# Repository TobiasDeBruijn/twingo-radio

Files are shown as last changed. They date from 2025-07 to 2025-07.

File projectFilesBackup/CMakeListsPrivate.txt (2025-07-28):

# !!! WARNING !!! AUTO-GENERATED FILE, PLEASE DO NOT MODIFY IT AND USE
# https://docs.platformio.org/page/projectconf/section_env_build.html#build-flags
#
# If you need to override existing CMake configuration or add extra,
# please create `CMakeListsUser.txt` in the root of project.
# The `CMakeListsUser.txt` will not be overwritten by PlatformIO.

set(CMAKE_CONFIGURATION_TYPES "nano_every" CACHE STRING "Build Types reflect PlatformIO Environments" FORCE)

# Convert "Home Directory" that may contain unescaped backslashes on Windows

SET(CMAKE_C_COMPILER "$ENV{HOME}/.platformio/packages/toolchain-atmelavr/bin/avr-gcc")
SET(CMAKE_CXX_COMPILER "$ENV{HOME}/.platformio/packages/toolchain-atmelavr/bin/avr-g++")
SET(CMAKE_CXX_FLAGS "-std=gnu++11 -fno-exceptions -fno-threadsafe-statics -fpermissive -Wno-error=narrowing -mmcu=atmega4809 -Os -w -ffunction-sections -fdata-sections -flto")
SET(CMAKE_C_FLAGS "-std=gnu11 -fno-fat-lto-objects -mmcu=atmega4809 -Os -w -ffunction-sections -fdata-sections -flto")

SET(CMAKE_C_STANDARD 11)
set(CMAKE_CXX_STANDARD 11)

if (CMAKE_BUILD_TYPE MATCHES "nano_every")
    add_definitions(-DPLATFORMIO=60002)
    add_definitions(-DARDUINO_AVR_NANO_EVERY)
    add_definitions(-DAVR_NANO_4809_328MODE)
    add_definitions(-DMILLIS_USE_TIMERB3)
    add_definitions(-DNO_EXTERNAL_I2C_PULLUP)
    add_definitions(-DF_CPU=16000000L)
    add_definitions(-DARDUINO_ARCH_MEGAAVR)
    add_definitions(-DARDUINO=10808)
    add_definitions(-DUSB_VID=0x2341)
    add_definitions(-DUSB_PID=0x0058)
    add_definitions(-DUSB_PRODUCT=\"Arduino\ Nano\ Every\")
    add_definitions(-DUSB_MANUFACTURER=\"Arduino\")

    include_directories("${CMAKE_CURRENT_LIST_DIR}/include")
    include_directories("${CMAKE_CURRENT_LIST_DIR}/src")
    include_directories("$ENV{HOME}/.platformio/packages/framework-arduino-megaavr/cores/arduino/api/deprecated")
    include_directories("$ENV{HOME}/.platformio/packages/framework-arduino-megaavr/cores/arduino")
    include_directories("$ENV{HOME}/.platformio/packages/framework-arduino-megaavr/variants/nona4809")
    include_directories("$ENV{HOME}/.platformio/packages/framework-arduino-megaavr/libraries/EEPROM/src")
    include_directories("$ENV{HOME}/.platformio/packages/framework-arduino-megaavr/libraries/SPI/src")
    include_directories("$ENV{HOME}/.platformio/packages/framework-arduino-megaavr/libraries/SoftwareSerial/src")
    include_directories("$ENV{HOME}/.platformio/packages/framework-arduino-megaavr/libraries/Wire/src")
    include_directories("$ENV{HOME}/.platformio/packages/toolchain-atmelavr/lib/gcc/avr/7.3.0/include")
    include_directories("$ENV{HOME}/.platformio/packages/toolchain-atmelavr/lib/gcc/avr/7.3.0/include-fixed")
    include_directories("$ENV{HOME}/.platformio/packages/toolchain-atmelavr/avr/include")

    FILE(GLOB_RECURSE EXTRA_LIB_SOURCES
        ${CMAKE_CURRENT_LIST_DIR}/.pio/libdeps/nano_every/*.*
    )
endif()

FILE(GLOB_RECURSE SRC_LIST
    ${CMAKE_CURRENT_LIST_DIR}/src/*.*
    ${CMAKE_CURRENT_LIST_DIR}/lib/*.*
    ${CMAKE_CURRENT_LIST_DIR}/test/*.*
)

list(APPEND SRC_LIST ${EXTRA_LIB_SOURCES})

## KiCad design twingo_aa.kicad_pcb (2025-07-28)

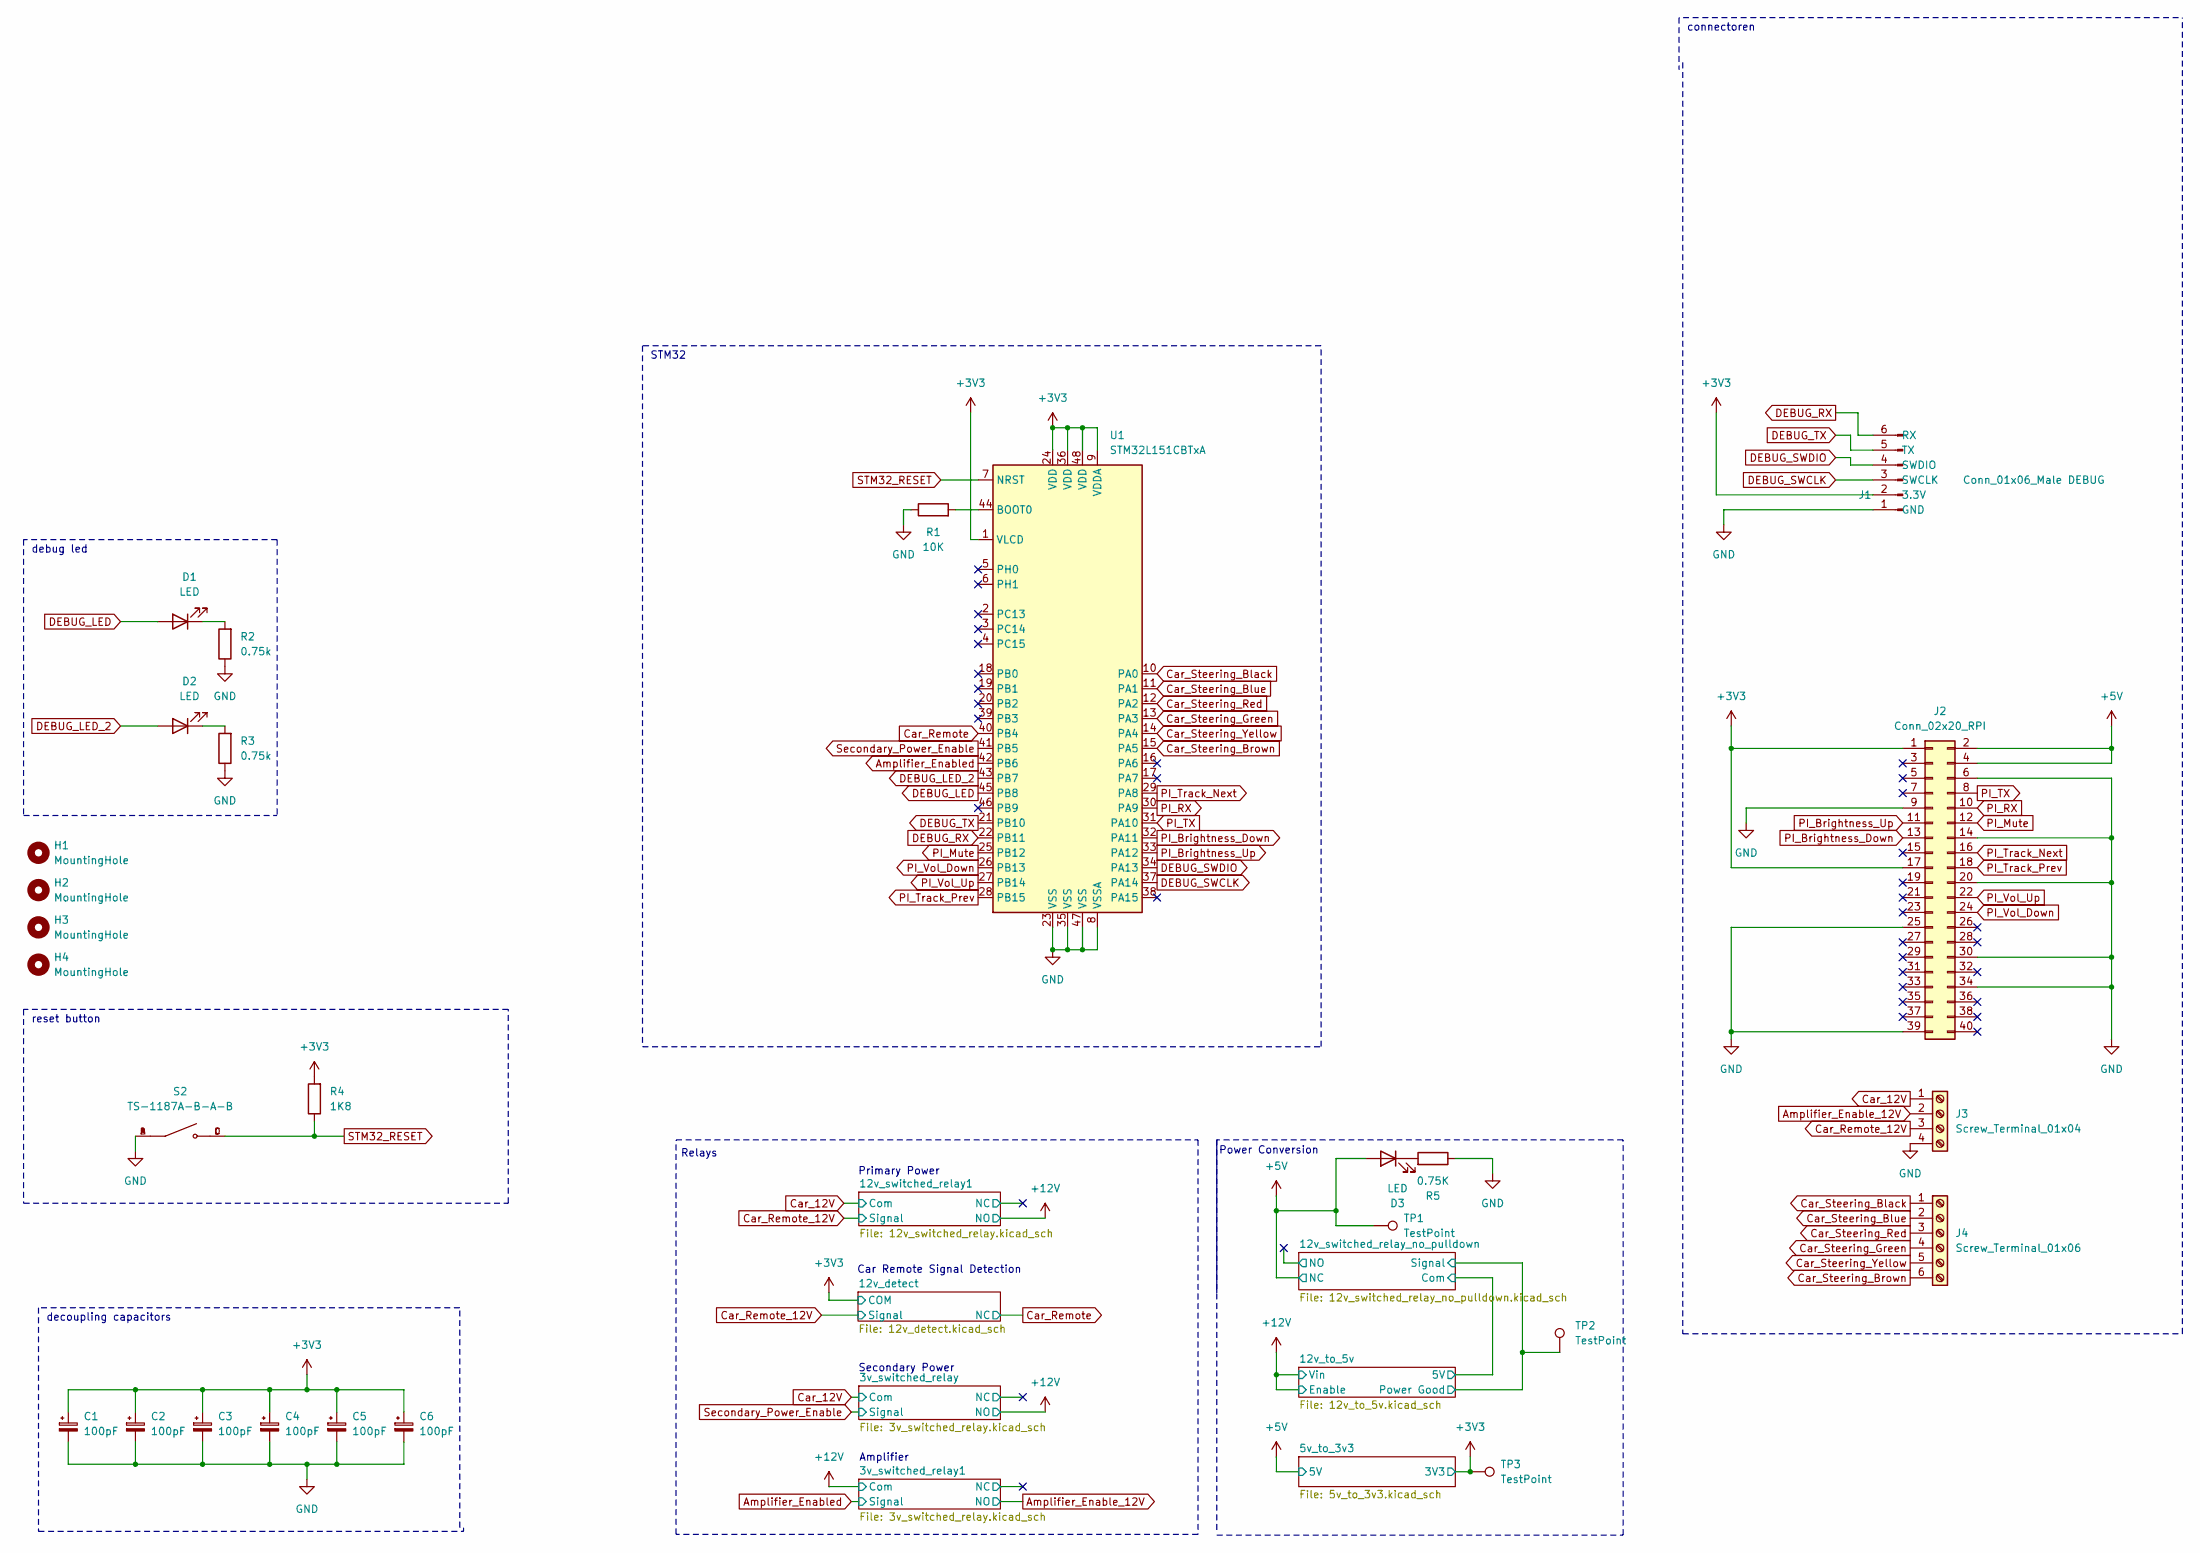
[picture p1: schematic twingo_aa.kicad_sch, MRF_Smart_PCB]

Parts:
C1, C2, C3, C4, C5, C6: 100pF; C_0805_2012Metric
D1, D2, D3: LED; LED_0805_2012Metric
H1, H2, H3, H4: MountingHole; MountingHole_2.5mm
J1: Conn_01x06_Male DEBUG; JST_SHL_SM06B-SHLS-TF_1x06-1MP_P1.00mm_Horizontal
J2: Conn_02x20_RPI; PinSocket_2x20_P2.54mm_Vertical
J3: Screw_Terminal_01x04; TerminalBlock_bornier-4_P5.08mm
J4: Screw_Terminal_01x06; TerminalBlock_bornier-6_P5.08mm
R1: 10K; R_1206_3216Metric
R2, R3: 0.75k; R_0603_1608Metric
R4: 1K8; R_0603_1608Metric
R5: 0.75K; R_0805_2012Metric
S2: TS-1187A-B-A-B; SW_TS-1187A-B-A-B; PARTREV A0
TP1, TP2, TP3: TestPoint; TestPoint_Pad_D1.0mm
U1: STM32L151CBTxA; LQFP-48_7x7mm_P0.5mm

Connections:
+3V3: C1.1, C2.1, C3.1, C4.1, C5.1, C6.1, J1.2 (3.3V), J2.1, J2.17, R4.2, TP3.1, U1.1 (VLCD), U1.9 (VDDA), U1.24 (VDD), U1.36 (VDD), U1.48 (VDD); also elsewhere on the board
+5V: D3.2 (A), J2.2, J2.4, TP1.1; also elsewhere on the board
/12v_switched_relay_no_pulldown/Signal: TP2.1; also elsewhere on the board
Amplifier_Enable_12V: J3.2; also elsewhere on the board
Amplifier_Enabled: U1.42 (PB6); also elsewhere on the board
Car_12V: J3.1; also elsewhere on the board
Car_Remote: U1.40 (PB4); also elsewhere on the board
Car_Remote_12V: J3.3; also elsewhere on the board
Car_Steering_Black: J4.1, U1.10 (PA0)
Car_Steering_Blue: J4.2, U1.11 (PA1)
Car_Steering_Brown: J4.6, U1.15 (PA5)
Car_Steering_Green: J4.4, U1.13 (PA3)
Car_Steering_Red: J4.3, U1.12 (PA2)
Car_Steering_Yellow: J4.5, U1.14 (PA4)
DEBUG_LED: D1.2 (A), U1.45 (PB8)
DEBUG_LED_2: D2.2 (A), U1.43 (PB7)
DEBUG_RX: J1.6 (RX), U1.22 (PB11)
DEBUG_SWCLK: J1.3 (SWCLK), U1.37 (PA14)
DEBUG_SWDIO: J1.4 (SWDIO), U1.34 (PA13)
DEBUG_TX: J1.5 (TX), U1.21 (PB10)
GND: C1.2, C2.2, C3.2, C4.2, C5.2, C6.2, J1.1 (GND), J2.6, J2.9, J2.14, J2.20, J2.25, J2.30, J2.34, J2.39, J3.4, R1.1, R2.1, R3.1, R5.1, S2.A, S2.B, U1.8 (VSSA), U1.23 (VSS), U1.35 (VSS), U1.47 (VSS); also elsewhere on the board
unnamed: D1.1 (K), R2.2
unnamed: D2.1 (K), R3.2
unnamed: D3.1 (K), R5.2
unnamed: R1.2, U1.44 (BOOT0)
PI_Brightness_Down: J2.13, U1.32 (PA11)
PI_Brightness_Up: J2.11, U1.33 (PA12)
PI_Mute: J2.12, U1.25 (PB12)
PI_RX: J2.10, U1.30 (PA9)
PI_TX: J2.8, U1.31 (PA10)
PI_Track_Next: J2.16, U1.29 (PA8)
PI_Track_Prev: J2.18, U1.28 (PB15)
PI_Vol_Down: J2.24, U1.26 (PB13)
PI_Vol_Up: J2.22, U1.27 (PB14)
STM32_RESET: R4.1, S2.C, S2.D, U1.7 (NRST)
Secondary_Power_Enable: U1.41 (PB5); also elsewhere on the board

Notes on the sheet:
decoupling capacitors
Relays
Amplifier
Car Remote Signal Detection
Secondary Power
Power Conversion
debug led
STM32
Primary Power
reset button
connectoren

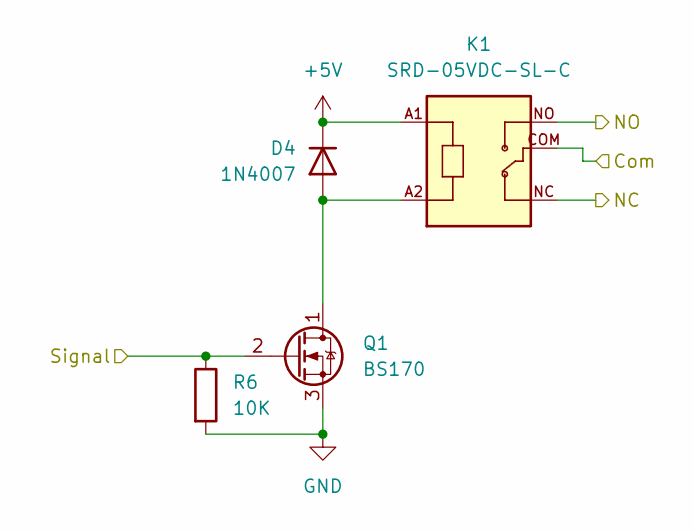
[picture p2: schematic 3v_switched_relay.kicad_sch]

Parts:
D4: 1N4007; D_DO-41_SOD81_P10.16mm_Horizontal
K1: SRD-05VDC-SL-C; RELAY_SRD-05VDC-SL-C
Q1: BS170; TO-92_Inline
R6: 10K; R_1206_3216Metric

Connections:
+5V: D4.1 (K), K1.A1; also elsewhere on the board
+12V: K1.NO; also elsewhere on the board
/3v_switched_relay/NC: K1.NC
Car_12V: K1.COM; also elsewhere on the board
GND: Q1.3 (S), R6.2; also elsewhere on the board
unnamed: D4.2 (A), K1.A2, Q1.1 (D)
Secondary_Power_Enable: Q1.2 (G), R6.1; also elsewhere on the board

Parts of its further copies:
D5: 1N4007; D_DO-41_SOD81_P10.16mm_Horizontal
K2: SRD-05VDC-SL-C; RELAY_SRD-05VDC-SL-C
Q2: BS170; TO-92_Inline
R7: 10K; R_1206_3216Metric

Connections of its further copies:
+5V: D5.1 (K), K2.A1; also elsewhere on the board
+12V: K2.COM; also elsewhere on the board
/3v_switched_relay1/NC: K2.NC
Amplifier_Enable_12V: K2.NO; also elsewhere on the board
Amplifier_Enabled: Q2.2 (G), R7.1; also elsewhere on the board
GND: Q2.3 (S), R7.2; also elsewhere on the board
unnamed: D5.2 (A), K2.A2, Q2.1 (D)

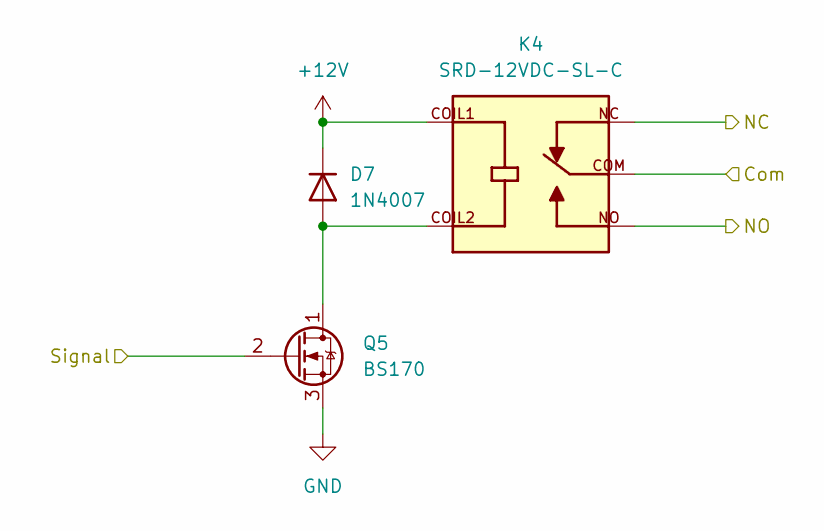
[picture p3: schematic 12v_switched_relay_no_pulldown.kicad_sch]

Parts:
D7: 1N4007; D_DO-41_SOD81_P10.16mm_Horizontal
K4: SRD-12VDC-SL-C; RELAY_SRD-12VDC-SL-C; PARTREV 1.0
Q5: BS170; TO-92_Inline

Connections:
+5V: K4.NC; also elsewhere on the board
+12V: D7.1 (K), K4.COIL1; also elsewhere on the board
/12v_switched_relay_no_pulldown/Com: K4.COM; also elsewhere on the board
/12v_switched_relay_no_pulldown/NO: K4.NO
/12v_switched_relay_no_pulldown/Signal: Q5.2 (G); also elsewhere on the board
GND: Q5.3 (S); also elsewhere on the board
unnamed: D7.2 (A), K4.COIL2, Q5.1 (D)

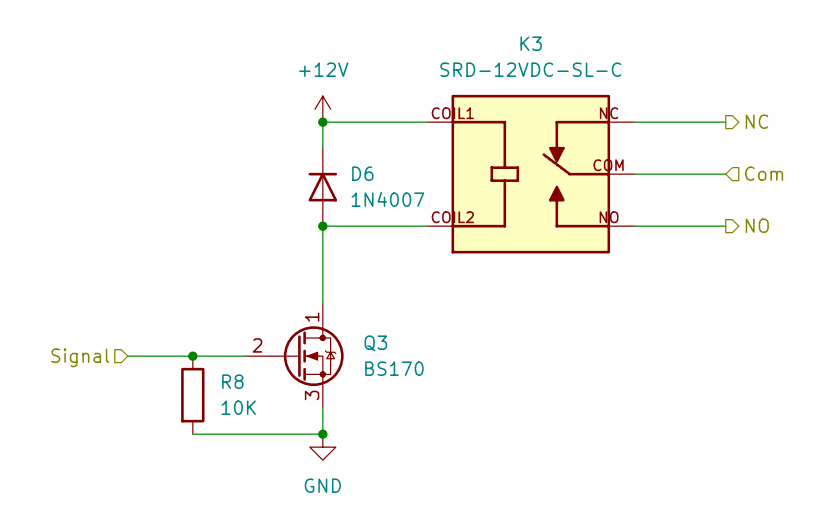
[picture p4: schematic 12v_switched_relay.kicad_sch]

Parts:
D6: 1N4007; D_DO-41_SOD81_P10.16mm_Horizontal
K3: SRD-12VDC-SL-C; RELAY_SRD-12VDC-SL-C; PARTREV 1.0
Q3: BS170; TO-92_Inline
R8: 10K; R_1206_3216Metric

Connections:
+12V: D6.1 (K), K3.COIL1, K3.NO; also elsewhere on the board
/12v_switched_relay1/NC: K3.NC
Car_12V: K3.COM; also elsewhere on the board
Car_Remote_12V: Q3.2 (G), R8.1; also elsewhere on the board
GND: Q3.3 (S), R8.2; also elsewhere on the board
unnamed: D6.2 (A), K3.COIL2, Q3.1 (D)

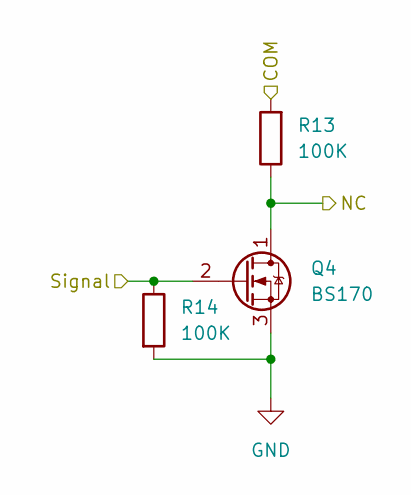
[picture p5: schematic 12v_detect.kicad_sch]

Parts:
Q4: BS170; TO-92_Inline
R13, R14: 100K; R_1206_3216Metric

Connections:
+3V3: R13.2; also elsewhere on the board
Car_Remote: Q4.1 (D), R13.1; also elsewhere on the board
Car_Remote_12V: Q4.2 (G), R14.1; also elsewhere on the board
GND: Q4.3 (S), R14.2; also elsewhere on the board

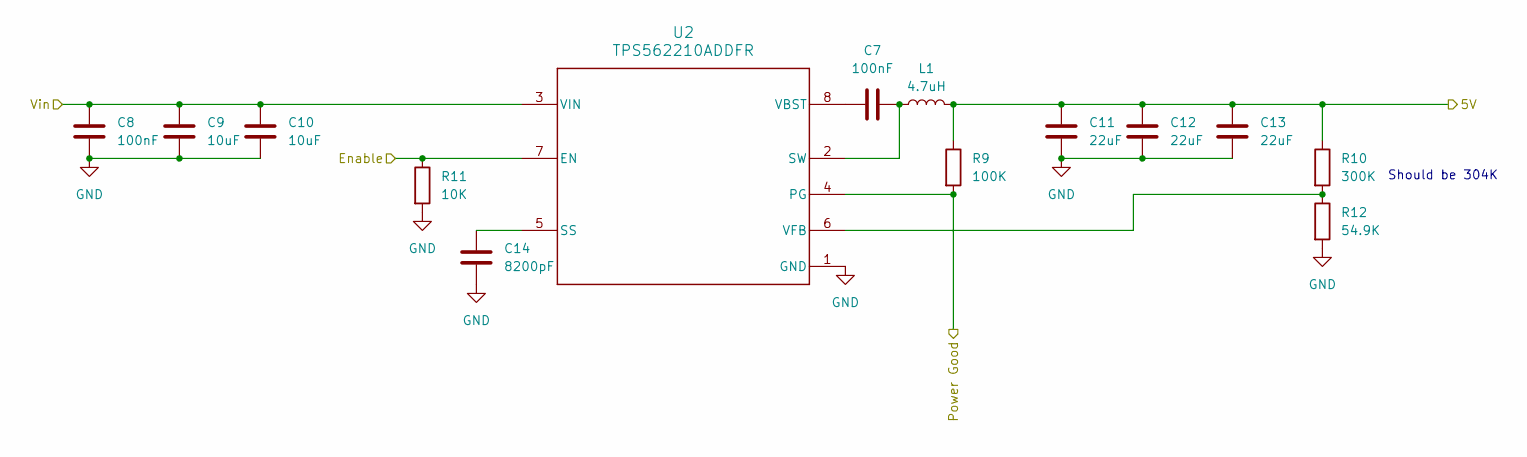
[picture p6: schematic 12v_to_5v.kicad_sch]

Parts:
C7, C8: 100nF; C_0402_1005Metric
C9, C10: 10uF; C_1206_3216Metric
C11, C12, C13: 22uF; C_1206_3216Metric
C14: 8200pF; C_0603_1608Metric
L1: 4.7uH; L_1206_3216Metric
R9: 100K; R_1206_3216Metric
R10: 300K; R_0603_1608Metric
R11: 10K; R_1206_3216Metric
R12: 54.9K; R_0402_1005Metric
U2: TPS562210ADDFR; TPS562210A_N

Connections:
+12V: C8.1, C9.1, C10.1, R11.1, U2.3 (VIN), U2.7 (EN); also elsewhere on the board
/12v_switched_relay_no_pulldown/Com: C11.2, C12.2, C13.2, L1.2, R9.1, R10.1; also elsewhere on the board
/12v_switched_relay_no_pulldown/Signal: R9.2, U2.4 (PG); also elsewhere on the board
GND: C8.2, C9.2, C10.2, C11.1, C12.1, C13.1, C14.2, R11.2, R12.2, U2.1 (GND); also elsewhere on the board
unnamed: C14.1, U2.5 (SS)
unnamed: C7.2, L1.1, U2.2 (SW)
unnamed: C7.1, U2.8 (VBST)
unnamed: R10.2, R12.1, U2.6 (VFB)

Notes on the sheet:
Should be 304K

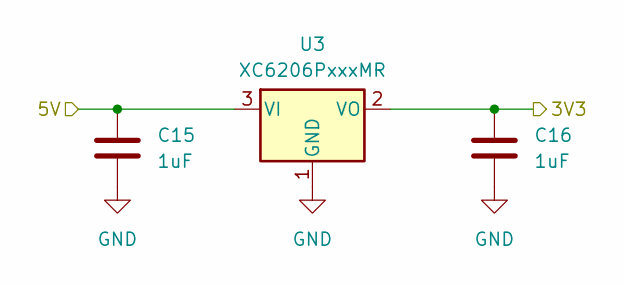
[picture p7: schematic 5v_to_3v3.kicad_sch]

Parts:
C15, C16: 1uF; C_1206_3216Metric
U3: XC6206PxxxMR; SOT-23-3

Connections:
+3V3: C16.1, U3.2 (VO); also elsewhere on the board
+5V: C15.1, U3.3 (VI); also elsewhere on the board
GND: C15.2, C16.2, U3.1 (GND); also elsewhere on the board

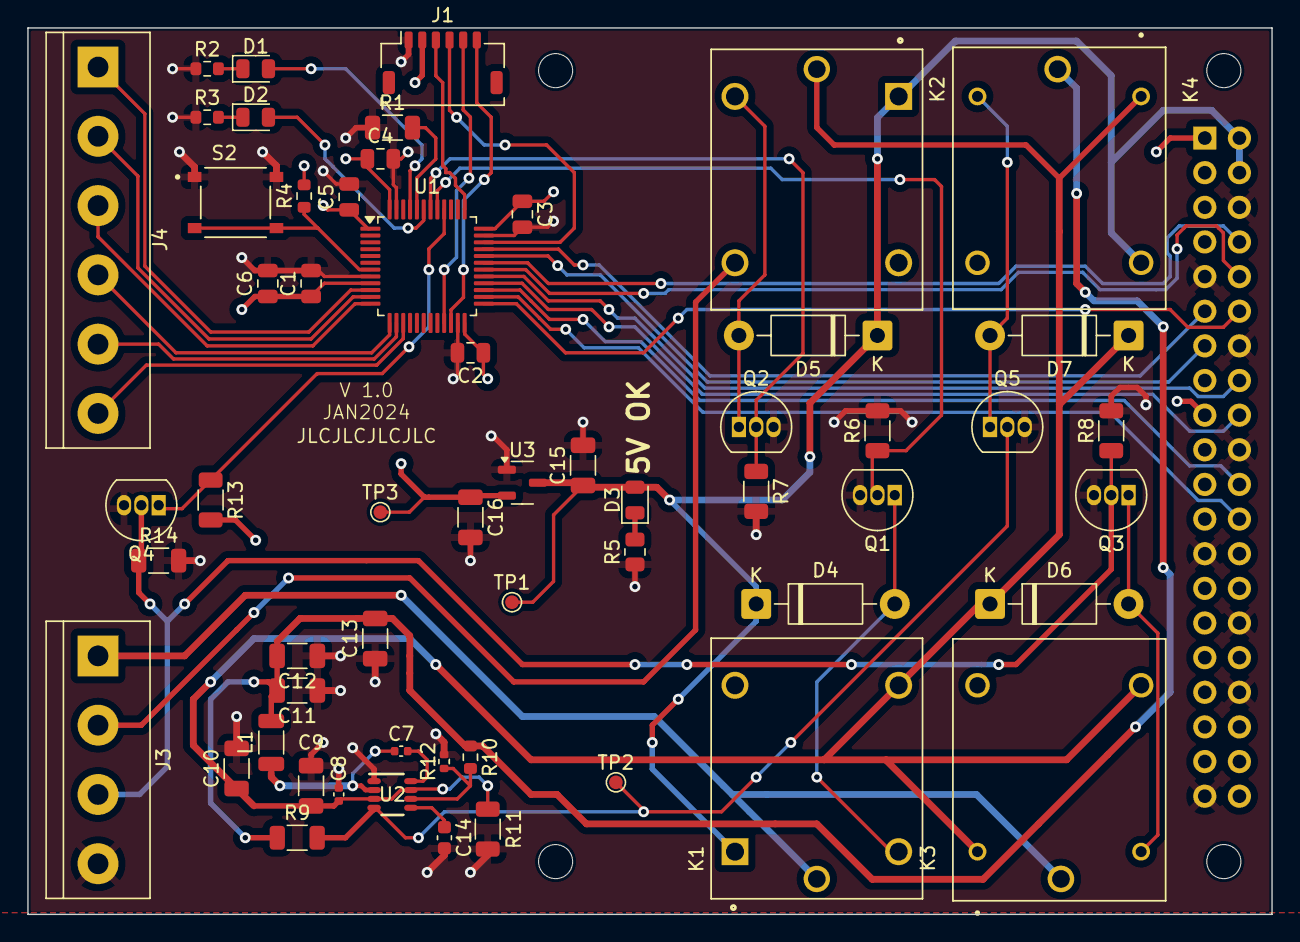
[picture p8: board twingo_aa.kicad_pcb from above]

Board: 4 copper layers, 91.2 x 65.0 mm, 62 parts (1 on the bottom side), 46 nets.

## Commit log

2025-07-28 Various fixes
    [12v_detect.kicad_sch, 12v_switched_relay.kicad_sch, 12v_switched_relay_no_pulldown.kicad_sch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]
2025-07-28 Most of the layout completed
    [12v_detect.kicad_sch, 12v_switched_relay.kicad_sch, 12v_switched_relay_no_pulldown.kicad_sch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]
